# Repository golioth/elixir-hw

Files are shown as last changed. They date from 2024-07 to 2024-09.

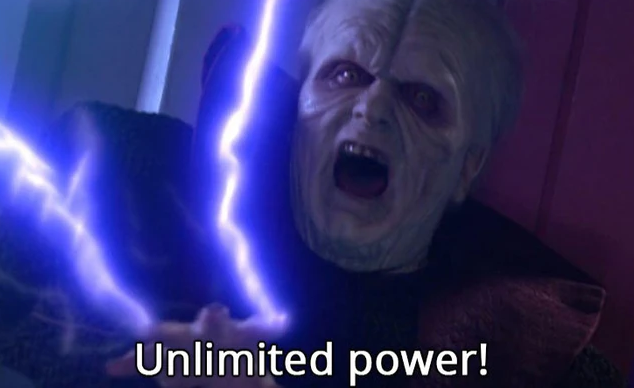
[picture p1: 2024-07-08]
input/images/Power.png

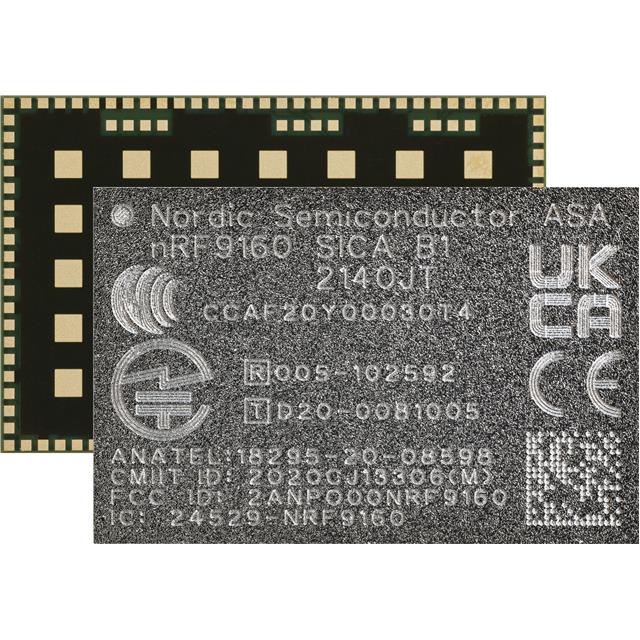
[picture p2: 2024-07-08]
input/images/MFG_NRF9160-SICA-B1A-R.jpg

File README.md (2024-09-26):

# Elixir
The Elixir is part of Golioth's "Aludel" platform, a family of devices that makes it easier to connect hardware to the internet using [Golioth's Firmware SDK](https://github.com/golioth/golioth-firmware-sdk) and [cloud platform](https://console.golioth.io). The Aludel family of devices are widely used in [Golioth's Reference Designs](https://projects.golioth.io), which are end-to-end demonstrations of IoT devices targeted at different vertical applications. 

This board primarily targets cellular connectivity but also has the ability to connect to/interact with WiFi networks; it can also be used for supplemental features such as [Wi-Fi locationing](https://blog.golioth.io/a-2-geofence-wi-fi-location-here-com-esp32-c3-golioth-pipelines-and-n8n/). An on-board power management unit facilitates a large array of power options, including LiPo via the onaboard connector and charging capabilities, but also up to 48V input for industrial applications. There are are array of sensors and other other commonly used support ICs. Prominently featured on Aludel boards, including this one, are [headers that conform to the MikroBus standard](https://www.mikroe.com/mikrobus). This is a pinout from Mikroelectronika and supported by their [wide range of plug-in sensor boards](https://www.mikroe.com/click). We chose this standard for maximum hardware swappability, enabling our users to change to a different targeted sensor or industry vertical by replacing one or two click boards. 

This is released as Revision C of the Elixir. Revisions A and B were internal-only and the naming will be maintained for continuity.

## On the board
* nRF9160 - Cat M1 / NB-IOT / GPS chip with dual core Cortex M33 processing
* ESP32-C3 - Running ESP-AT firmware, interfaced to the nRF9160 over UART
* BME280 - Weather sensor from Bosch, common to many Golioth designs
* Power
  * Low quiescent buck circuit, inherited from Feather Board
  * 5V boost to service the 5V output on the MikroBus
  * Battery charging
  * Fuel gauge
  * High voltage input (5.5V to 48V) for powering from things like OBD-II and industrial supplies
* LIS2DH - Accelerometer, inherited from Feather board
* PWM Buzzer - Allow audible indication [similar to the Thingy91](https://github.com/golioth/thingy91-golioth)
* Real Time Clock
* Secure Element
* Power Switching - Power switch of 3V3 for sensor nodes to shut down in low power situations
* QWIIC / STEMMA Headers - External sensors and peripherals including the [Aludel Ostentus](https://github.com/golioth/ostentus-hw)
* ClickBus headers
* USB C interface and power
* External SIM connector
* Multiple programming interfaces
  * 10 pin SWD (02x05 .127mm pitch), accessible from outside the case
  * 10 pin SWD Tag Connect (accessible from the top side of the board)
  * USB using the serial bootloader / MCUBoot

## The Aludel form factor

The Aludel form factor (Originally the "Aludel Mini" form factor) is based around the [Bud Boxes CU-1937-MB](https://www.budind.com/product/general-use-boxes/utilibox-style-l-series-utility-boxes-2/cu-1937-mb). This was further customized with a milled alternative ordered custom from Digikey, [described in more detail in this blog post](https://blog.golioth.io/low-volume-high-mix-mechanical-enclosures-for-iot-projects/). There are inserts that are 3D printed to target specific applications/Click boards, and a custom PCB front panel called [the Aludel Ostentus](https://github.com/golioth/ostentus-hw), which also is OSHW.

### Rev B Photos
Aludel_Elixir_RevB_Top
Aludel_Elixir_RevB_Bottom

## Purchase

The Elixir board is not available to purchase. Please contact [devrel@golioth.io](mailto:devrel@golioth.io) if you would like to arrange help with your manufacturing. 

## Usage with Reference Designs

[The Elixir is supported natively in the Reference Design Template](https://github.com/golioth/reference-design-template?tab=readme-ov-file#golioth-aludel-elixir). To use it in a build run the command:

`west build -p -b aludel_elixir/nrf9160/ns --sysbuild app`

## Hardware Lineage and License

This design was derived from [Jared Wolff's open source nRF9160 Feather board](https://github.com/circuitdojo/nrf9160-feather) and extended to fit the Aludel platform size. Additional items were added and some features removed or modified to fit the needs of Golioth Reference Designs

This board is released under the [CERN OHL-P (v2) license](https://opensource.org/license/cern-ohl-p). See [LICENSE](https://github.com/golioth/elixir-hw/blob/main/LICENSE) for more info.

Any replication or modification of this design must remove references to Golioth and The Golioth Logo, which is a trademark of Golioth, Inc.

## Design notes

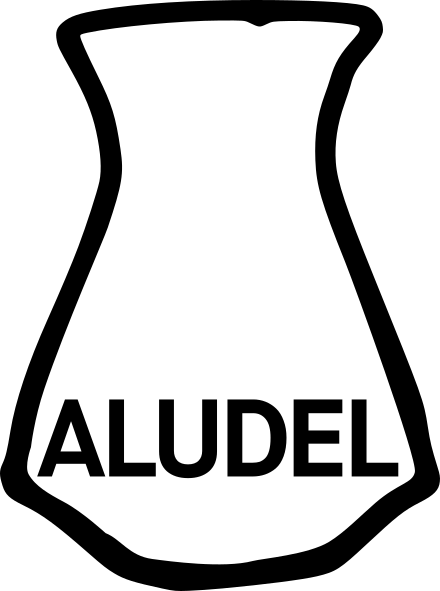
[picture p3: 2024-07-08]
input/images/aludel_5mm_3000px.png

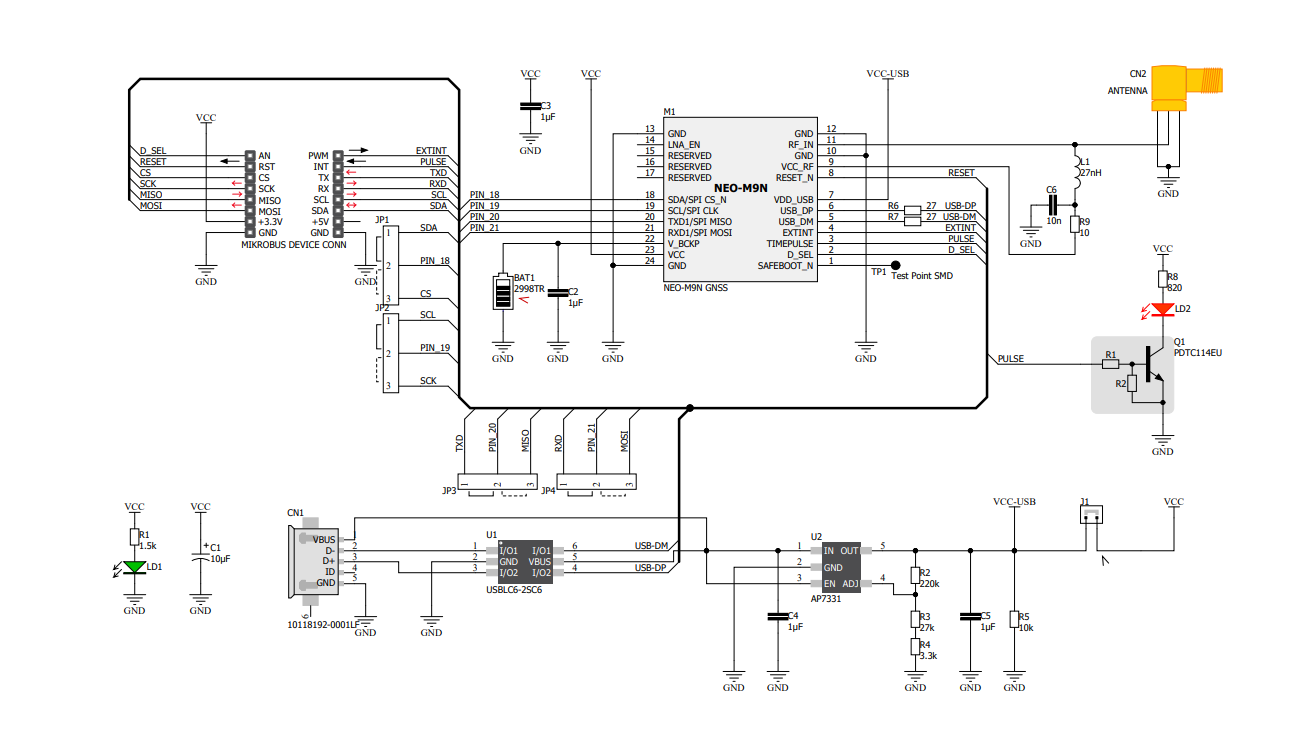
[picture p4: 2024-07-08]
input/images/GNSS7.png

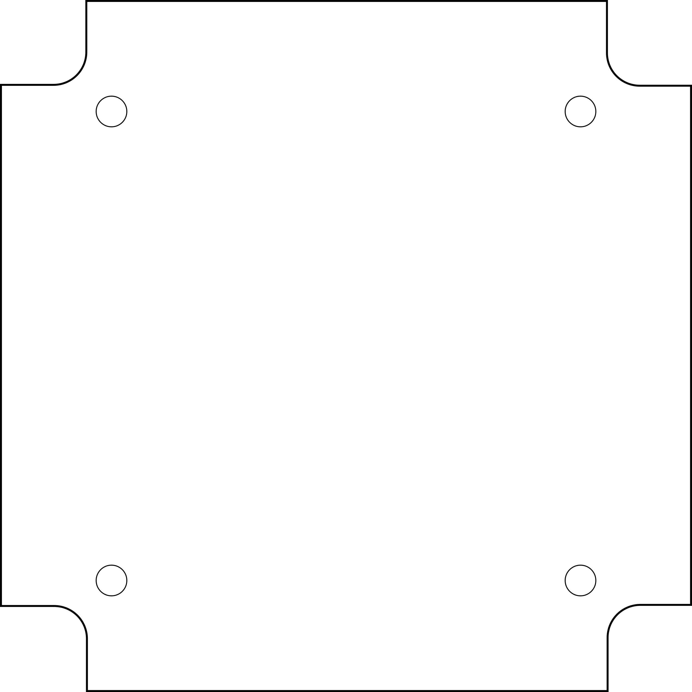
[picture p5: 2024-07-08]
input/mech/board-outline.png

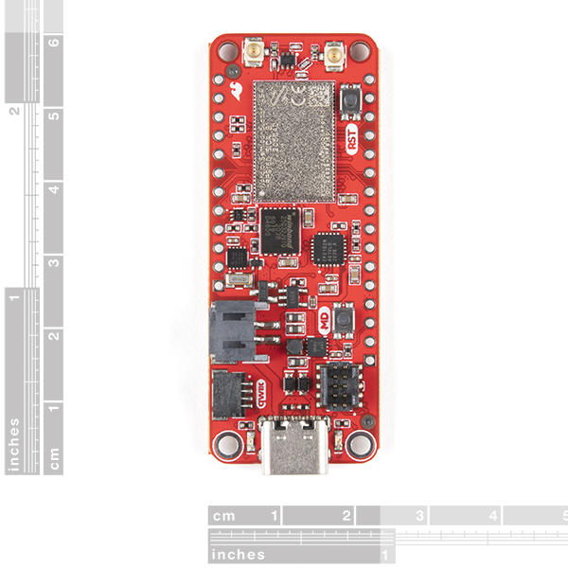
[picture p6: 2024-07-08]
input/mech/thing_plus_nrf9160_dimensions.jpg

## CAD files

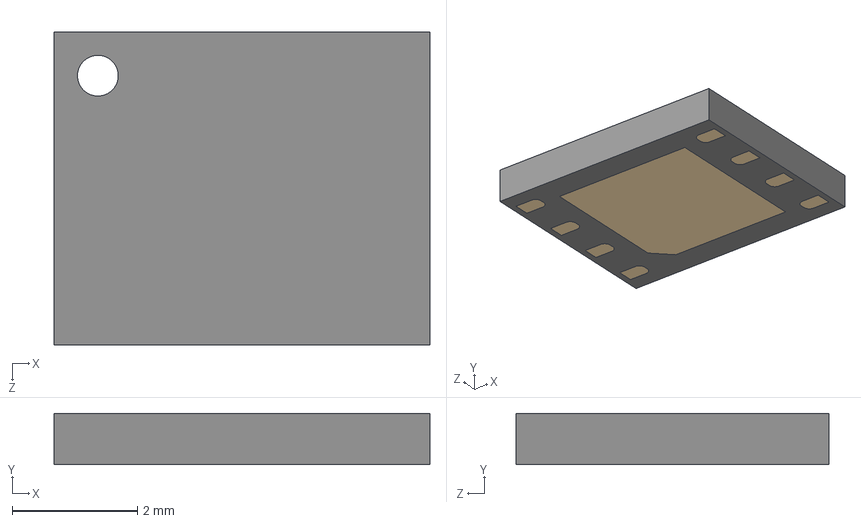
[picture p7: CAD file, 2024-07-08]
input/3d/SIM-E-MFF2-GL-250.step
6.00 x 0.82 x 5.00 mm

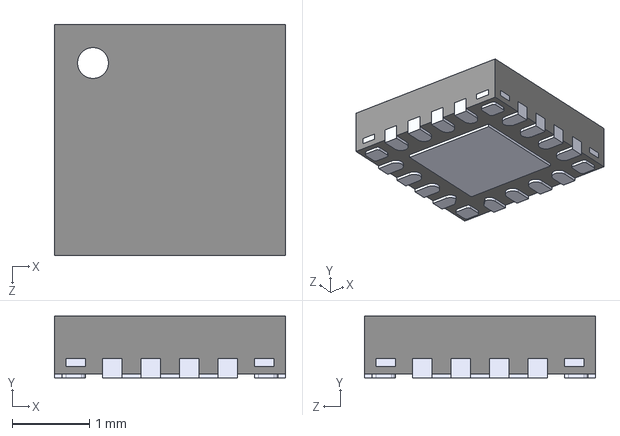
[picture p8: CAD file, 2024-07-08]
input/3d/CP2102N-A02-GQFN20.step
3.00 x 0.8 x 3.00 mm

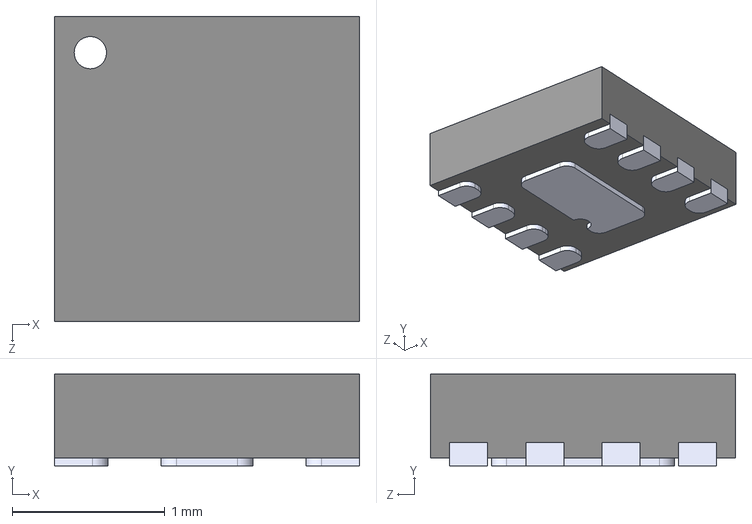
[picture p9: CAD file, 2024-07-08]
input/3d/MIC2288YML-TR.step
2.00 x 0.6 x 2.00 mm

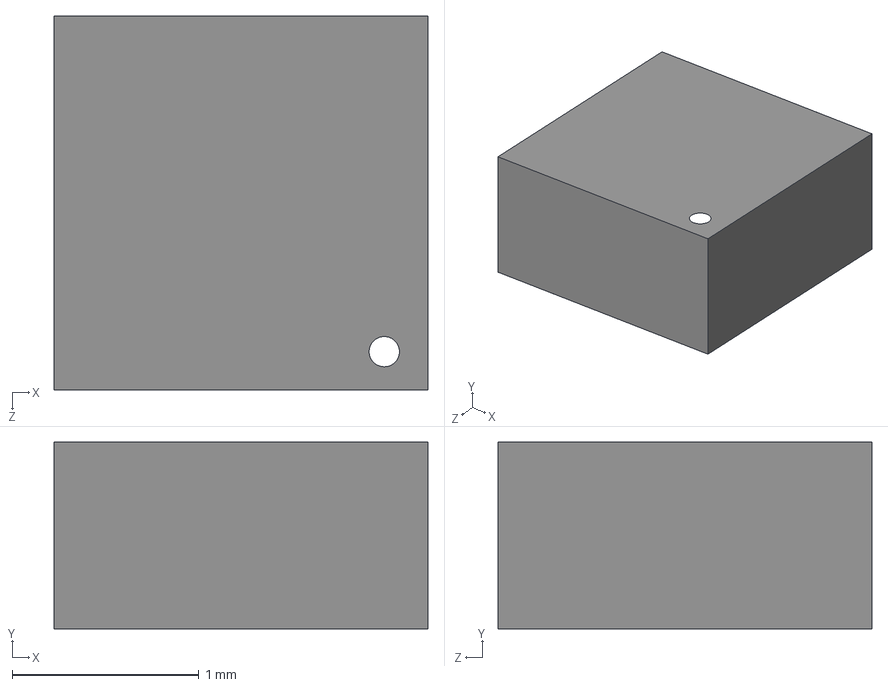
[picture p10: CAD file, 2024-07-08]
input/3d/LIS2DH12.step
2.00 x 1.00 x 2.00 mm

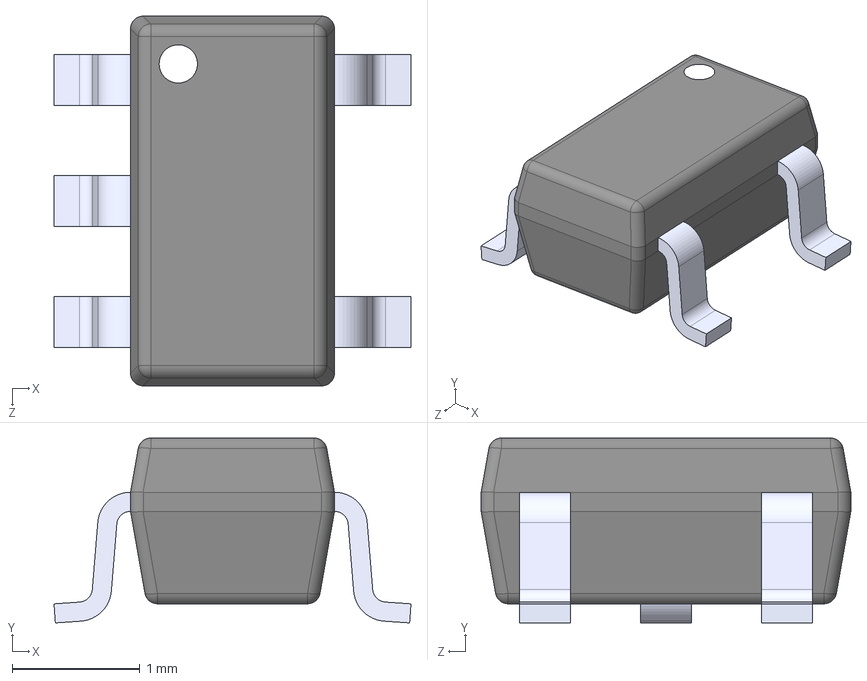
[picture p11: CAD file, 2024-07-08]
input/3d/SN74AUC1G66DBVR.step
2.80 x 1.45 x 2.90 mm

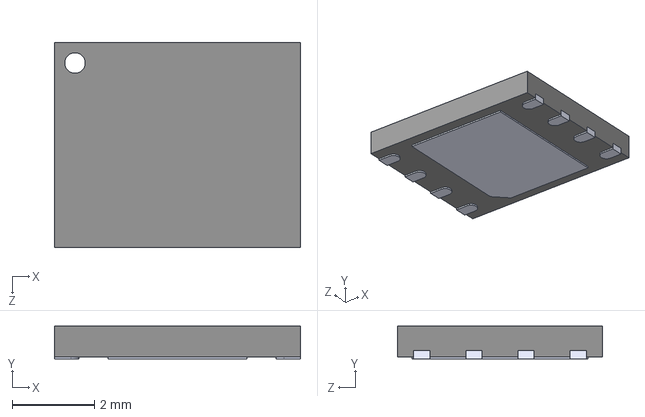
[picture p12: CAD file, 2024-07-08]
input/3d/W25Q32JVZPIQ.step
6.00 x 0.8 x 5.00 mm

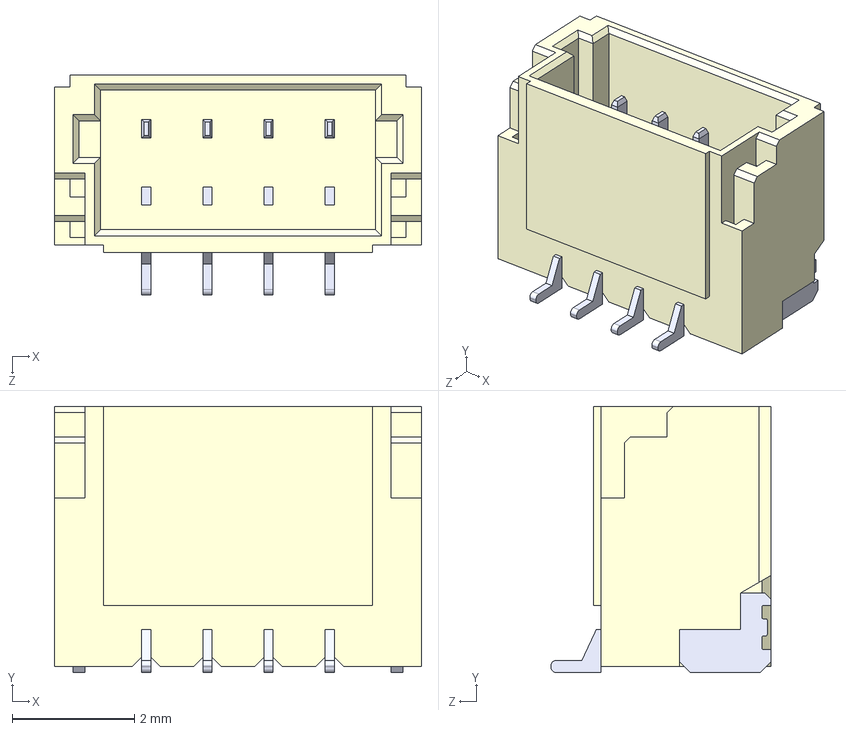
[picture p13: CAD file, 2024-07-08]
input/3d/BM04B-SRSS-TB-LF--SN---3DModel-STEP-56544.STEP
6.00 x 4.35 x 3.60 mm

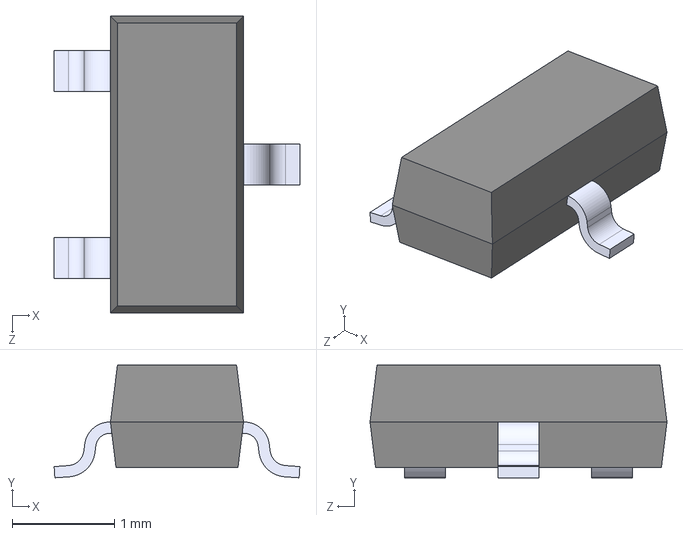
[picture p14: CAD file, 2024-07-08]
input/3d/DMG2301L-7.step
2.40 x 1.10 x 2.90 mm

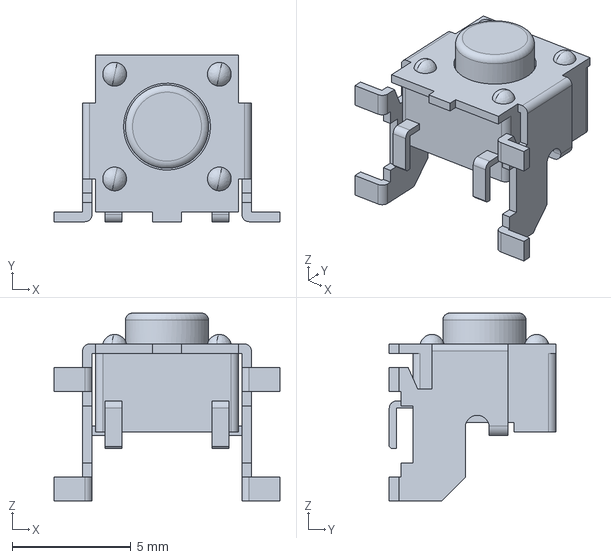
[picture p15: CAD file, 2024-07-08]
input/3d/PTS645VM13SMTR92LFS.stp
9.50 x 7.00 x 7.90 mm

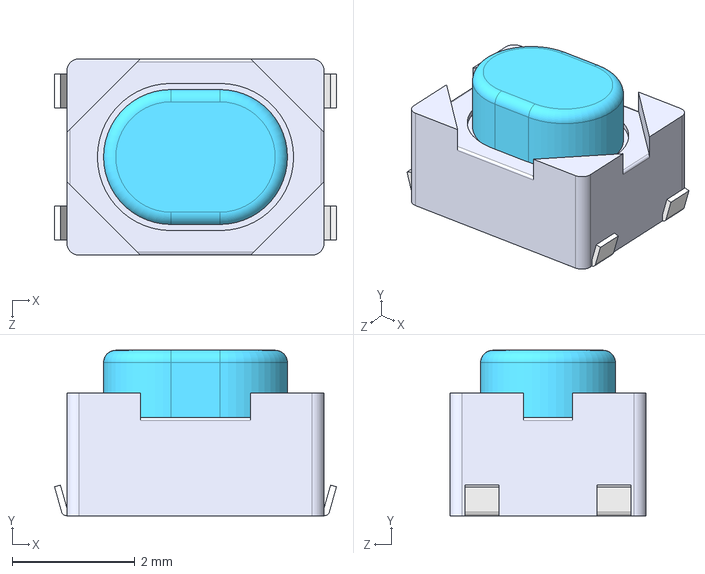
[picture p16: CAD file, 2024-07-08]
input/3d/PTS810SJK250SMTRLFS--3DModel-STEP-56544.STEP
4.60 x 2.70 x 3.20 mm

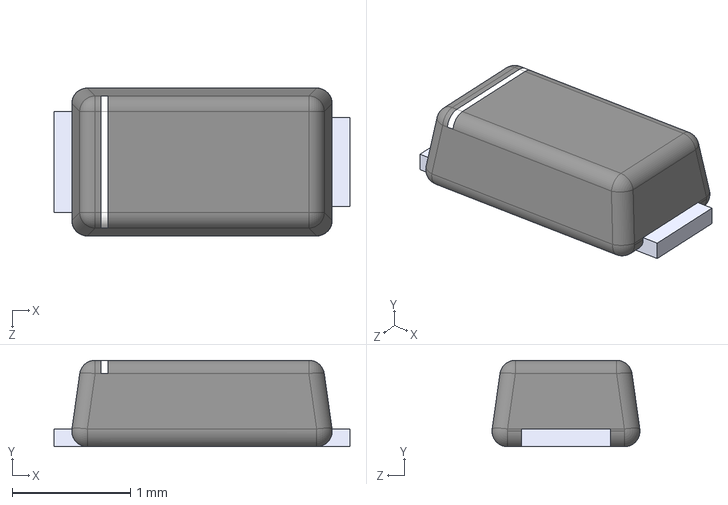
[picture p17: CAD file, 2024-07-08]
input/3d/SS14M.step
2.50 x 0.73 x 1.25 mm

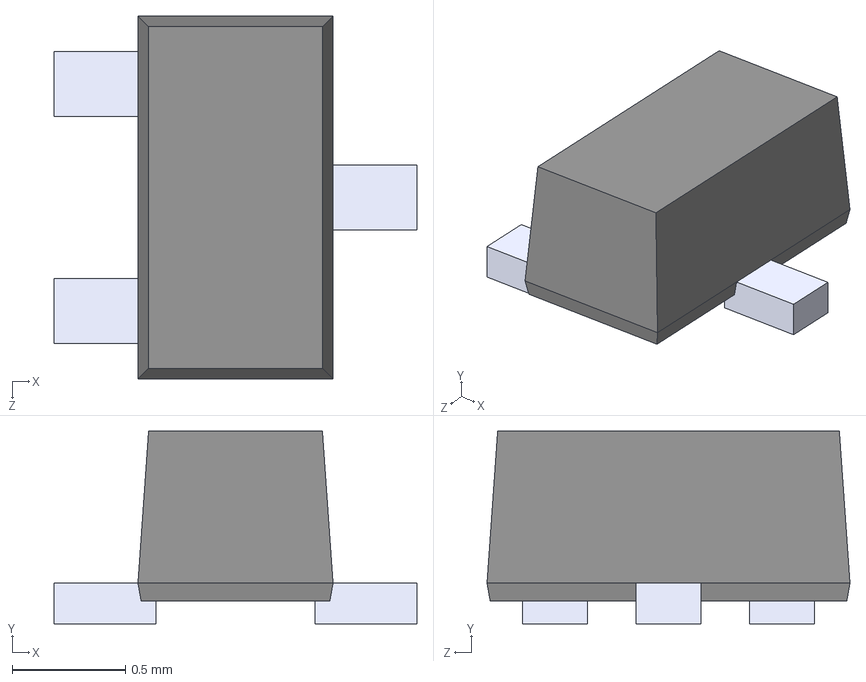
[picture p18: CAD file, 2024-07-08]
input/3d/RE1C002UNTCL.step
1.60 x 0.85 x 1.60 mm

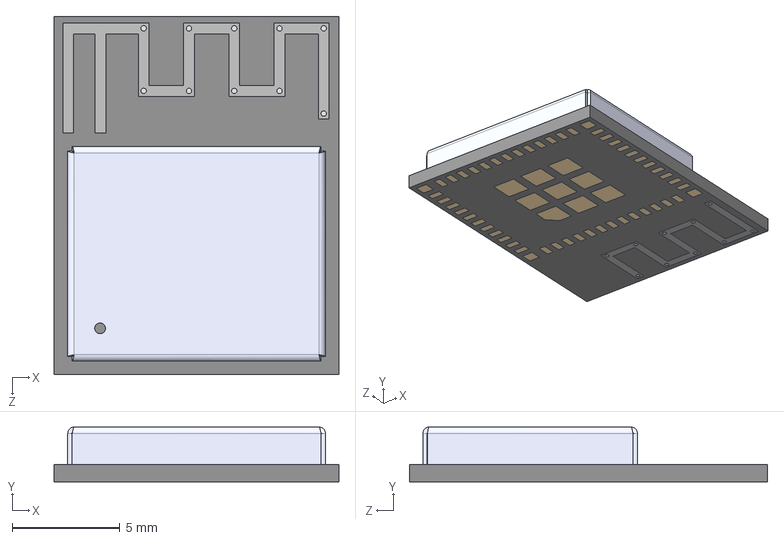
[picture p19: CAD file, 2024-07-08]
input/3d/ESP32-C3-MINI-1-N4.step
13.2 x 2.55 x 16.6 mm

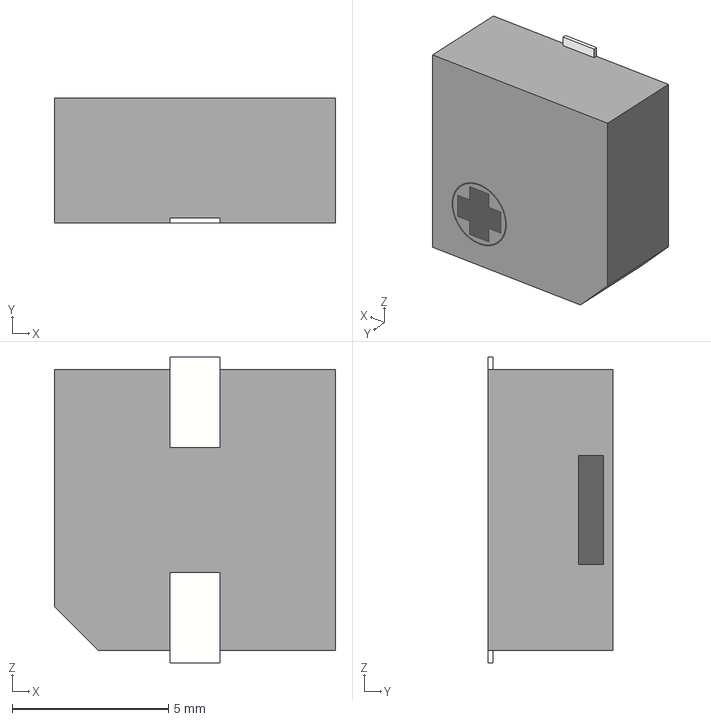
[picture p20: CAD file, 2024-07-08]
input/3d/SMT-0927-S-12-R.step
9.00 x 4.01 x 9.80 mm

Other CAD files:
input/3d/MIC2288YD5-TR.step
input/3d/LQH32CN4R7M33L.step
input/3d/DX07S016JA1R1500.step
input/3d/EVQ-P7L01P.step
input/3d/104224-0820.step
input/3d/1825640000.stp
input/3d/JS202011JAQN.step
input/3d/LMR16030SDDAR.STEP
input/3d/MAX17262REWL_T.step
input/3d/NRF9160-SIBA-R.step
input/3d/PCF85063ATL.STEP
input/3d/TPS62840DLCR.step

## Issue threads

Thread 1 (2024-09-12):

Slight misalignment of mounting holes

ChrisGammell, 2024-09-12:
During a livestream (https://www.youtube.com/watch?v=aSaus1-wG10) we found a misalignment of the holes on the elixir board and the expected footprint from the case vendor. Slight adjustments should make everything work a bit better. Currently there are no issues with fit, but only because of the "slop" we have in the size of the holes and the fasteners that we're using.

ChrisGammell, 2025-02-13:
Did overlay again, think this was fixed in a previous rev.

Closed 2025-02-13.

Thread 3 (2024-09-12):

Move power switch further from the USB connector

ChrisGammell, 2024-09-12:
It is currently quite difficult to make a cover for the small cover switch that fits "in line" with the USB connector. Consider moving the switch further away from the USB to give it more room on the back panel.

Closed 2025-02-15.

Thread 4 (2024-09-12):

Change color and location of the 3v3 and 5V LEDs

ChrisGammell, 2024-09-12:
Currently when the device is powered on via the USB connector and the power switch is engaged, there are two LEDs directly next to one another. This is unfortunate for being able to glance and see the power mode we're in.

Closed 2025-02-15.

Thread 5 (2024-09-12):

Make 3V3 LED controlled from the processor

ChrisGammell, 2024-09-12:
We have power draw when these LEDs are on and have no way of powering them off, so consider some kind of rational power switch scheme to turn off LEDs in a production-like environment (aside from depopulating). Consider making the 3V3 a "user" LED that is switchable from the main processor, so it can be tri-stated in low power modes.

ChrisGammell, 2025-02-13:
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

Added connection for 3V3 power LED (still red, charge indicator is now green, 5V now blue) to the P0.12/MD pin. That pin is normally used for setting the mode at boot, to put the device into MCUboot mode. We don't use it after boot (though the nRF9160 Feather used it as a diode indicator). After boot and configuration, the pin will be set to output low and the 3V3 LED will turn on. In a low power/battery situation, that pin will be tri-stated and no current should be drawn. In theory it could also be used in a "blinking" scenario if needed, though there are better tools for that. Pushing the MODE button on the board edge should light up that LED at any time, allowing for in-situ checks of the 3v3 rail, as would be the case if an nRF91 is misbehaving and you wanted to test if power was present without pulling out a DMM.

If none of this works, swapping the population option of R60 and R504 will take it back to previous operation.

Closed 2025-02-15.

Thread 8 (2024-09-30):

Move C48 and C52 and make keepout area for SIM card

ChrisGammell, 2024-09-30:
The capacitors that are "behind" the SIM card holder on the top side of the elixir make it difficult to plug in a sim card, since it wants to be flat against the PCB while inserting. Move the listed components and add a keepout.

Closed 2025-02-15.

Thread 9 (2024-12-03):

Add a method to measure incoming voltage for high power supply

ChrisGammell, 2024-12-03:
This would be useful for a solar panel plugged into the board, which has been proven to work with a simple 6V panel (but with unknown charge state)

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

IvoBCD, 2025-07-01:
Maybe https://www.mikroe.com/vcp-monitor-click might work for this ?

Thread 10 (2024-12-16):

Move charging LED indicator to top side of board

ChrisGammell, 2024-12-16:
Can't see if it's charging when in the case

Recommended placement is right next to the 2 mm JST

Closed 2025-02-15.

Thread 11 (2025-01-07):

Move power switch away from USB port

ChrisGammell, 2025-01-07:
The power switch is so close to the USB port that the switch cover created to protrude from the plastic needs to have a very small 'lip' to it. Moving the switch away from the USB port will help to remedy this situation. The existing design was because of the interplay between buttons on the top and the USB port and power switch on the bottom, as seen in the photos of the board

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

Switching the location of the Aludel logo and the power switch _should_ be a relatively low impact way to give more room, but it should also be checked against the 3D model in the case.

ChrisGammell, 2025-02-15:
Closed in commits referenced above

Closed 2025-02-15.

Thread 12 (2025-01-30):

BOM Consolidation

MarcoCiau, 2025-01-30:
Hi,

First of all, thanks for the awesome project! I'm really excited to work with it.

I've encountered an issue related to inconsistent component values between the BOM and the schematic in the KiCad design.

For example:

Component C41: The value in the schematic is 10uF, but the part number in the generated BOM shows 2.2uF.

I'd like to ask if there is an official-released BOM file to cross-reference and verify the correct values. This would help clarify whether this is a mistake in the schematic or the BOM generation process.

If the component value in the BOM is correct, I'd be happy to help by updating the schematic to match the BOM.

Regards!

MarcoCiau, 2025-01-30:
@ChrisGammell

ChrisGammell, 2025-01-30:
Hey Marco! Thanks for pointing out the error. There is no officially released BOM, the expectation is that the schematic is the control document, as opposed to a standalone BOM. Obviously I need to rectify C41 though! I would happily accept PRs though.

Are you planning to build some units?

MarcoCiau, 2025-01-30:
Hi Chris,Thanks for the quick reply!

Yes, we're planning to build some units for an MVP IoT monitoring project using the Golioth platform. We're working on finalizing the BOM for the PCB manufacturer, and the discrepancies between the schematic and the BOM are making things difficult.

If it's possible, could we take a look at the BOM from the last board manufacturing run (from Golioth)? It would really help us align everything, and once we have it, we’d be happy to update the schematic and contribute a fixed version.

Let me know if you need anything from our side to help with the process!

Cheers!

MarcoCiau, 2025-01-30:
Hi, I'm back again :)

I finally figured out the 'issue' and submitted a PR #13

Thanks!

ChrisGammell, 2025-02-07:
Closed after merging #13

Closed 2025-02-07.

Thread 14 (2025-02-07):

Add clearance around JST 2 mm battery connector (J4)

ChrisGammell, 2025-02-07:
3 mm from the edge of the copper on the through hole pads to any components on the back. Need to move R71, R72, C6 minimum.

This will allow automated soldering of the through hole component

Closed 2025-02-15.

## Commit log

2025-02-07 Update C34 & C41 values: Changed 10µF to 2.2µF per LMR16030 input capacitor guidelines.
    [elixir-power.kicad_sch]
2025-02-15 Layout after session 5 of the live stream
    [104224-0820.step, 1909763-1.step, 20021122-00010T4LF.step]
2025-02-15 Moved power switch away from USB. Fixes #3 and #11.
2025-02-15 Move charging LED to front side of PCB near 3v3 and 5V leds. Fixes #10
2025-02-15 Added keepout around J4 for selective solder. Fixes #14
2025-02-15 Move ATECC to rev C. Fixes #2.
    [elixir-sensors.kicad_sch]
2025-02-15 Change power resistor colors and add lower value resistors for higher drop LEDs. Fixes #4. Keeping location the same.
    [elixir-nrf9160.kicad_sch, elixir-power.kicad_sch, elixir.kicad_sch]
2025-02-15 Routed 3V3 to P0.12/MD line on nRF9160 to be able to show power status after boot. Fixes #5, will add more details there
    [elixir-power.kicad_sch]
2025-02-15 add 3d models for sim holder, hv connector
    [104224-0820.step, 1825640000.stp]

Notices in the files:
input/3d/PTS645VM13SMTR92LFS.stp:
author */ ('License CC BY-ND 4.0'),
